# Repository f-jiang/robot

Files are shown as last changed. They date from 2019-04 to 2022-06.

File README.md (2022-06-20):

# Mobile Robot

[BOM](https://docs.google.com/spreadsheets/d/1hAyx_H2yaLHObjr3c2HcGa4GbXQhFF7O3Fq-fULQeV0/edit?usp=sharing)
[Google Drive](https://drive.google.com/drive/folders/1Uw0iWY_K3mZgV3rem3GLMkO6ajqQ58nl)

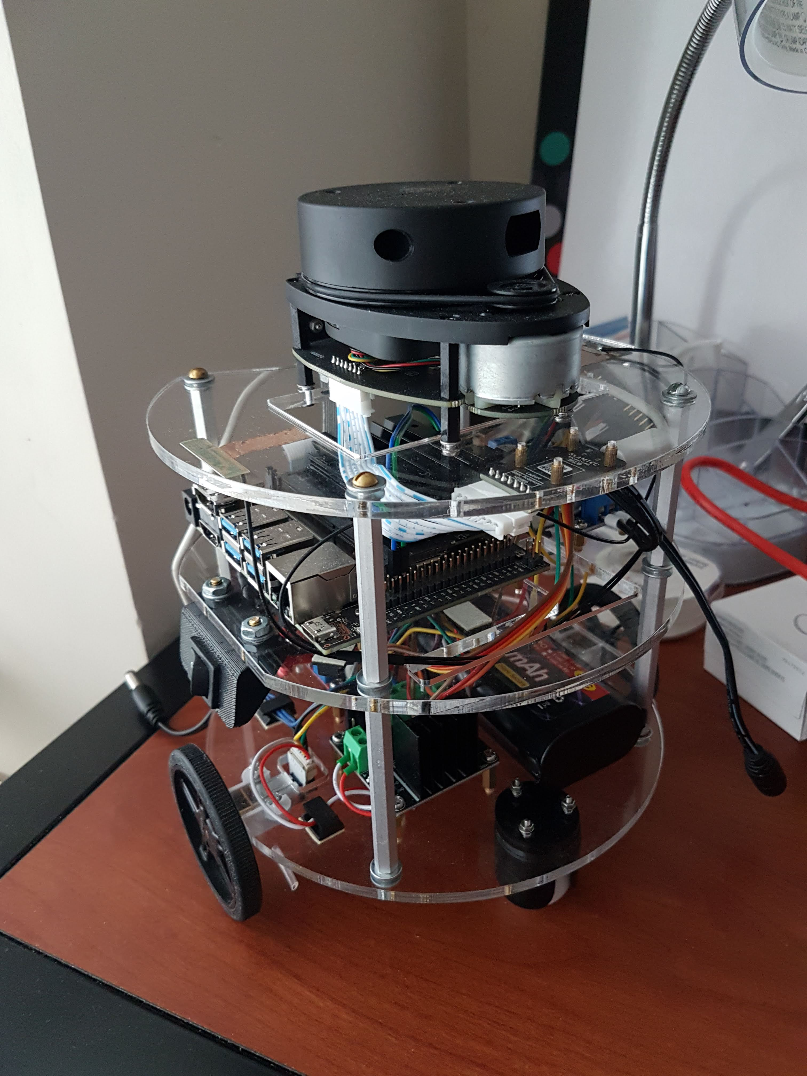
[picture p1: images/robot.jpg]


### Contributors:

- Feilan Jiang
- Matt Strong
- Tejit Pabari
- Satish Upadhyaya

## Requirements

- ROS Melodic

## Setup

```bash
# create a catkin workspace
mkdir -p catkin_ws/src
cd catkin_ws/src
git clone https://github.com/f-jiang/robot
cd ..

# automatically install the packages
rosdep install --from-paths src --ignore-src -r -y

# build the workspace
catkin build 
# or catkin_make

# it is recommended to add the below line to your ~/.bashrc
source devel/setup.bash
```

## Running the Simulation 

```bash
# run the simulation
roslaunch world_name:=worlds/rooms.world use_gazebo:=true robot_base base.launch

# run teleop; keyboard controls will start in same terminal window
roslaunch use_gazebo:=true robot_control teleop.launch
```

This is how the simulation should look:

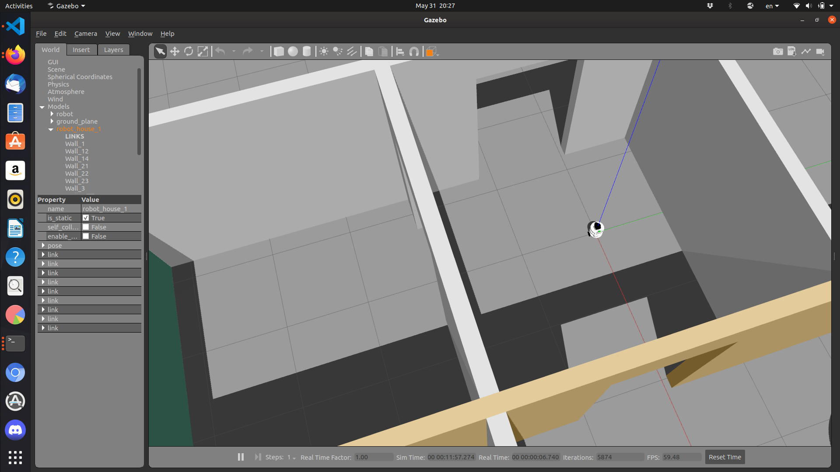
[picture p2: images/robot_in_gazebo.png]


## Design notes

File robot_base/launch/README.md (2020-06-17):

# `robot_base` launch files

- `base.launch`: Top-level launch file. Starts up all nodes required to interface with robot actuators and sensors, whether in real-life or simulation. Also loads robot description to allow for publishing of tf frames. Can be launched directly (will need to provide a `cmd_vel` msg).
- `drive_base.launch`: Launches nodes required to drive the robot, whether in real-life or simulation. Can be launched directly if wishing to drive the physical robot without sensors, and will need to provide a `cmd_vel` msg.
- `sensors_base.launch`: Launches sensors on the physical robot. Can be launched directly, although `tf` won't work.
- `robot_hw.launch`: Launches firmware node and PID controllers on the physical robot. Not meant to be launched directly.
- `tune_pid.launch`: Utility for tuning robot's PID controllers.

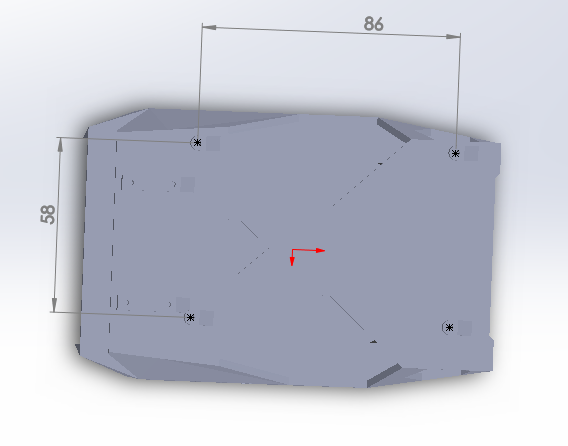
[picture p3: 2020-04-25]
cad/misc/Screenshot_1.png

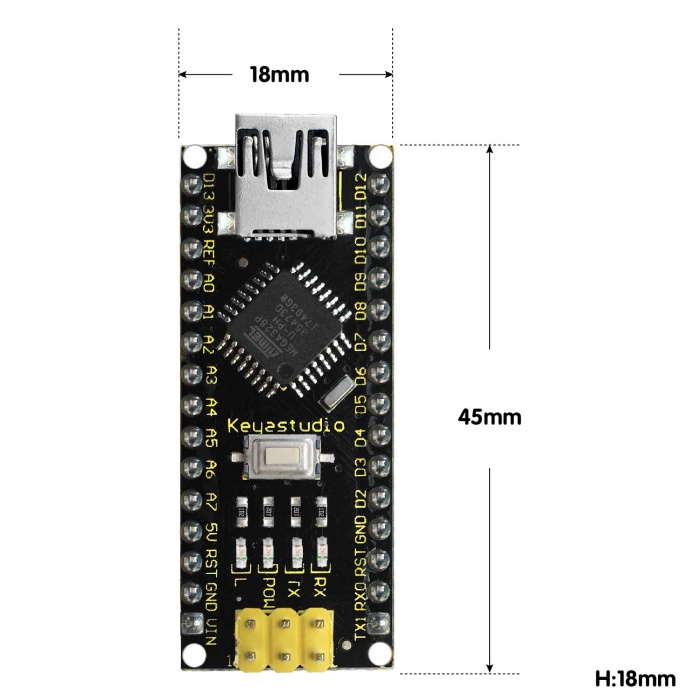
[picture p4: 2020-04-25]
cad/misc/700px-Ks0173_size.jpg

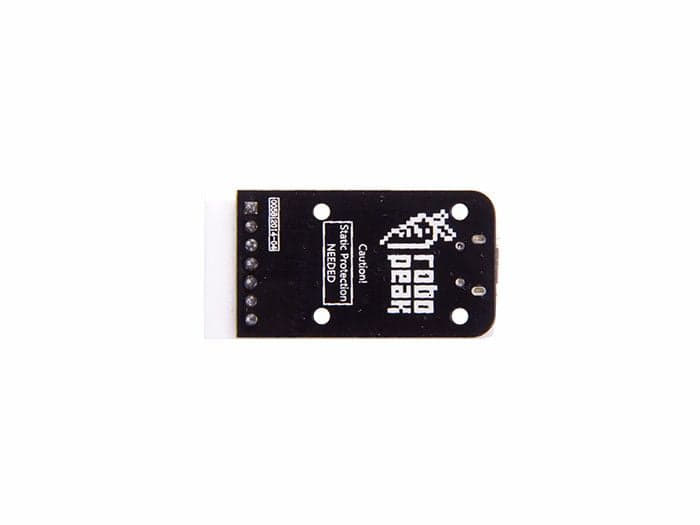
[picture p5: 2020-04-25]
cad/misc/lidar-usb-board.jpg

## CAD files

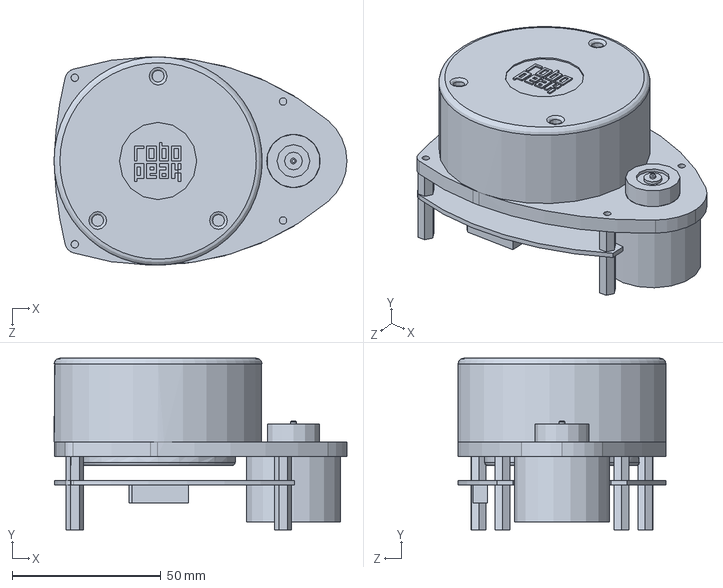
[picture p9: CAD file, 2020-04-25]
cad/ext parts/RPLidar_by_RoboPeak/files/rplidar_main.SLDPRT
98.5 x 57.7 x 70.0 mm

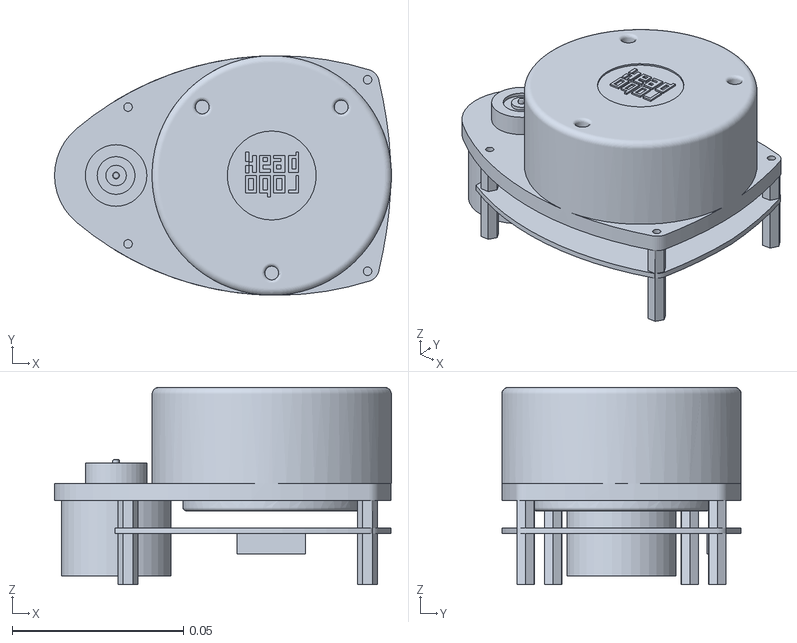
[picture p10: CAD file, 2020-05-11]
robot_description/meshes/rplidar_main.STL
0.0985 x 0.07 x 0.0577

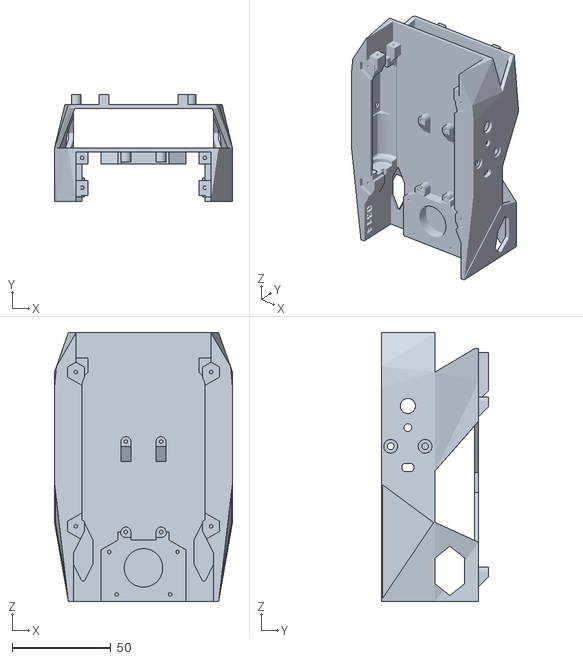
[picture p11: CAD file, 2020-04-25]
cad/ext parts/chassis.stl
90.0 x 54.0 x 136.0

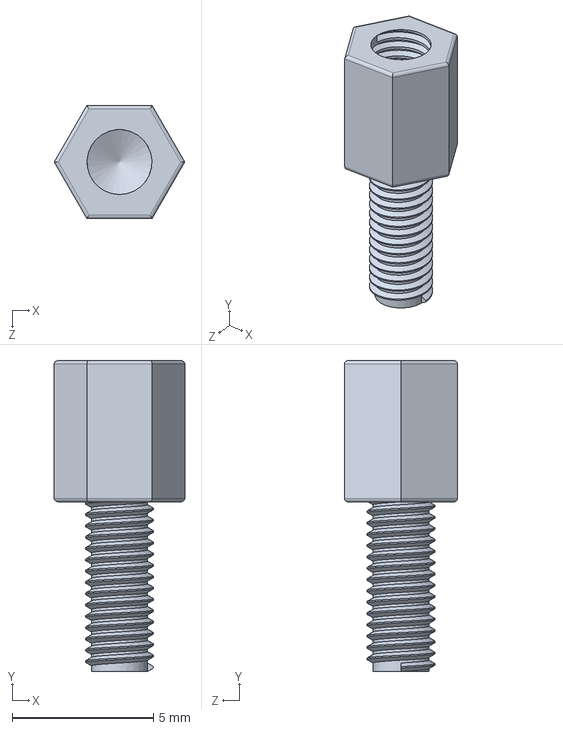
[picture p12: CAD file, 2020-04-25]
cad/ext parts/M2 Standoff mf.SLDPRT
4.62 x 11.0 x 4.00 mm

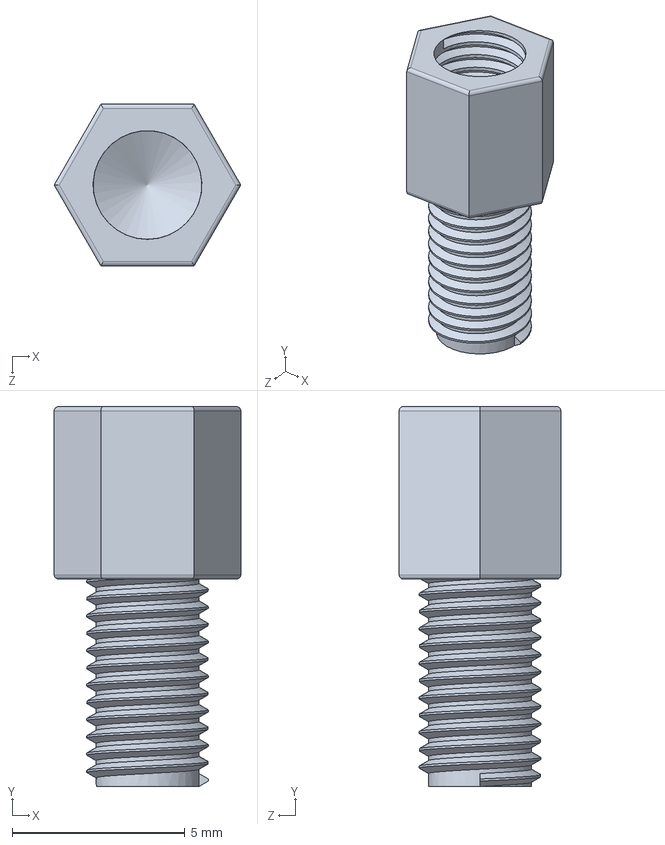
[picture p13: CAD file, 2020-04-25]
cad/ext parts/M3 Standoff mf.SLDPRT
5.40 x 11.0 x 4.68 mm

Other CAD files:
cad/export dwg/chassis-top-v2.DWG
cad/export dwg/chassis-mid.DWG
cad/export dwg/chassis-top.DWG
cad/3d print/camera-mount.SLDPRT
cad/3d print/export stl/arduino-nano-mount.STL
cad/3d print/export stl/camera-mount.STL
cad/3d print/export stl/caster-spacer 2.STL
cad/3d print/export stl/caster-spacer.STL
cad/3d print/export stl/old/camera-mount-slide-fit.STL
cad/3d print/export stl/switch-mount.STL
cad/3d print/old/camera-mount-slide-fit-old.SLDPRT
cad/3d print/old/camera-mount-slide-fit.SLDPRT
cad/3d print/old/camera-mount-snap-fit.SLDPRT
cad/arduino-nano-mount.SLDPRT
cad/battery.SLDPRT
cad/buck-drivetrain.SLDPRT
cad/caster.SLDPRT
cad/chassis.SLDPRT
cad/computer-buck.SLDPRT
cad/ext parts/RPLidar_by_RoboPeak/files/rplidar_main.STL
cad/imu.SLDPRT
cad/jetson.SLDPRT
cad/l298.SLDPRT
cad/lidar-adapter.SLDPRT
cad/lidar.SLDPRT
cad/motor-and-encoder.SLDPRT
cad/motor-bracket.SLDPRT
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

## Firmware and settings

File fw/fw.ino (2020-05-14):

#include <ros.h>
#include <std_msgs/Float64.h>

#include <stdio.h>

#include <Arduino.h>

// NOTE: currently this lib and the encoder code here rely on an unreleased fix for the arduino mbed core:
// https://github.com/arduino/ArduinoCore-nRF528x-mbedos/pull/69
#include <QuadratureEncoder.h>  // fork: f-jiang/QuadratureEncoder

// #define DEBUG

#define MOTOR_LB    8   // left backwards
#define MOTOR_LF    9   // left forward
#define MOTOR_RB    6   // right backwards
#define MOTOR_RF    7   // right forward
#define MOTOR_SLEEP 10
#define MOTOR_FAULT 11

#define ENC_LEFT_A  4
#define ENC_LEFT_B  5
#define ENC_RIGHT_A 2
#define ENC_RIGHT_B 3

#define ENC_PULSES_PER_REVOLUTION (51.45 * 12)

Encoders encLeft(ENC_LEFT_A, ENC_LEFT_B);
Encoders encRight(ENC_RIGHT_A, ENC_RIGHT_B);
unsigned long encLastTime;
long positionLeft = 0;
long positionRight = 0;

int loopDelay = 10;

char buf[256];

#ifndef DEBUG
// TODO integrate this into catkin so that robot_constants can be used here

ros::NodeHandle nh;

std_msgs::Float64 leftPosMsg;
ros::Publisher pubLeftPos("/left_wheel/pos", &leftPosMsg);

std_msgs::Float64 rightPosMsg;
ros::Publisher pubRightPos("/right_wheel/pos", &rightPosMsg);

std_msgs::Float64 leftVelMsg;
ros::Publisher pubLeftVel("/left_wheel/vel", &leftVelMsg);

std_msgs::Float64 rightVelMsg;
ros::Publisher pubRightVel("/right_wheel/vel", &rightVelMsg);

void leftEffCallback(const std_msgs::Float64& msg);
void rightEffCallback(const std_msgs::Float64& msg);
ros::Subscriber<std_msgs::Float64> subLeftEff("/left_wheel/control_effort", &leftEffCallback);
ros::Subscriber<std_msgs::Float64> subRightEff("/right_wheel/control_effort", &rightEffCallback);

int controlFrequency = 100;

void setMotor(byte fwdPin, byte bkdPin, short val) {
    short absVal = abs(val);
    if (val > 0) {
        analogWrite(fwdPin, absVal);
        analogWrite(bkdPin, 0);
    } else {
        analogWrite(fwdPin, 0);
        analogWrite(bkdPin, absVal);
    }
}

void leftEffCallback(const std_msgs::Float64& msg) {
    setMotor(MOTOR_LF, MOTOR_LB, round(msg.data));
}

void rightEffCallback(const std_msgs::Float64& msg) {
    setMotor(MOTOR_RF, MOTOR_RB, round(msg.data));
}
#endif

// rad/s
float angularVelocity(const long& oldPosition,
                      const long& newPosition,
                      const unsigned long& oldTime,
                      const unsigned long& newTime) {
    return (newPosition - oldPosition)
           / ENC_PULSES_PER_REVOLUTION
           * (PI * 2)
           / ((newTime - oldTime) / 1000.0f);
}

float angularPosition(const long& position) {
    long wrappedPosition = position
                           - static_cast<long>(position / ENC_PULSES_PER_REVOLUTION)
                           * ENC_PULSES_PER_REVOLUTION;

    if (position < 0) {
        wrappedPosition += ENC_PULSES_PER_REVOLUTION;
    }

    return wrappedPosition
           / ENC_PULSES_PER_REVOLUTION
           * (PI * 2);
}

void setup()
{
#ifdef DEBUG
    Serial.begin(115200);
#endif

    pinMode(MOTOR_SLEEP, OUTPUT);
    pinMode(MOTOR_FAULT, INPUT);
    pinMode(MOTOR_LB, OUTPUT);
    pinMode(MOTOR_LF, OUTPUT);
    pinMode(MOTOR_RB, OUTPUT);
    pinMode(MOTOR_RF, OUTPUT);

    // motors off
    analogWrite(MOTOR_LB, 0);
    analogWrite(MOTOR_LF, 0);
    analogWrite(MOTOR_RB, 0);
    analogWrite(MOTOR_RF, 0);

    // disable low-power sleep mode
    digitalWrite(MOTOR_SLEEP, HIGH);

#ifndef DEBUG
    nh.initNode();

    nh.advertise(pubLeftPos);
    nh.advertise(pubRightPos);
    nh.advertise(pubLeftVel);
    nh.advertise(pubRightVel);

    nh.subscribe(subLeftEff);
    nh.subscribe(subRightEff);

    while (!nh.connected()) {
        nh.spinOnce();
    }

    // TODO robot_constants::params::kControlFrequency
    nh.getParam("/control_frequency", &controlFrequency);
    sprintf(buf, "fw_node running at %d hz", controlFrequency);
    nh.loginfo(buf);
    loopDelay = round(1000 / static_cast<double>(controlFrequency));
#endif

    delay(1000);
}

void loop()
{
    long newPositionLeft, newPositionRight;
    float angularPositionLeft, angularPositionRight;
    float angularVelocityLeft, angularVelocityRight;
    newPositionLeft = -encLeft.getEncoderCount();
    newPositionRight = encRight.getEncoderCount();
    unsigned long encNow = millis();
    angularVelocityLeft = angularVelocity(positionLeft, newPositionLeft, encLastTime, encNow);
    angularVelocityRight = angularVelocity(positionRight, newPositionRight, encLastTime, encNow);
    angularPositionLeft = angularPosition(newPositionLeft);
    angularPositionRight = angularPosition(newPositionRight);

#ifdef DEBUG
    sprintf(buf,
            "pos_l: %6d, e_l: %6d, theta_l (deg): %4f, omega_l (deg/s): %8.2f, n_l (rpm): %8.2f, "
                "pos_r: %6d, e_r: %6d, theta_r (deg): %4f, omega_r (deg/s): %8.2f, n_r (rpm): %8.2f\n",
            newPositionLeft,
            encLeft.getEncoderErrorCount(),
            angularPositionLeft * 180 / PI,
            angularVelocityLeft * 180 / PI,
            angularVelocityLeft / (2 * PI) * 60,
            newPositionRight,
            encRight.getEncoderErrorCount(),
            angularPositionRight * 180 / PI,
            angularVelocityRight * 180 / PI,
            angularVelocityRight / (2 * PI) * 60);
    Serial.print(buf);
#endif

    encLastTime = encNow;
    positionLeft = newPositionLeft;
    positionRight = newPositionRight;

#ifndef DEBUG
    leftPosMsg.data = angularPositionLeft;
    pubLeftPos.publish(&leftPosMsg);
    rightPosMsg.data = angularPositionRight;
    pubRightPos.publish(&rightPosMsg);

    leftVelMsg.data = angularVelocityLeft;
    pubLeftVel.publish(&leftVelMsg);
    rightVelMsg.data = angularVelocityRight;
    pubRightVel.publish(&rightVelMsg);

    nh.spinOnce();
#endif

    delay(loopDelay);
}

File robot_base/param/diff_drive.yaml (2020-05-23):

type        : "diff_drive_controller/DiffDriveController"
left_wheel  : 'base_to_left_wheel_joint'  # joint 0
right_wheel : 'base_to_right_wheel_joint' # joint 1
pose_covariance_diagonal : [0.001, 0.001, 1000000.0, 1000000.0, 1000000.0, 1000.0]  # TODO adjust
twist_covariance_diagonal: [0.001, 0.001, 1000000.0, 1000000.0, 1000000.0, 1000.0]

wheel_separation : 0.17923
wheel_radius : 0.03

linear:
  x:
    has_velocity_limits: true
    max_velocity: 0.5
angular:
  z:
    has_velocity_limits: true
    max_velocity: 1.5

# TODO publish rate /control_frequency
base_frame_id: base_link
enable_odom_tf: true
odom_frame_id: odom
publish_cmd: true

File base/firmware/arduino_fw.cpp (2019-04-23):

#include <Arduino.h>

#include <Encoder.h>

#define private public
#include <PID_v1.h>
#undef private

// TODO set and correct all names
#define MOTOR_LEFT_EN 11    // EN_B
#define MOTOR_RIGHT_EN 10   // EN_A
#define MOTOR_IN_1 6
#define MOTOR_IN_2 9
#define MOTOR_IN_3 12
#define MOTOR_IN_4 13

// ENC PINS
#define ENC_LEFT_A  2
#define ENC_LEFT_B  7
#define ENC_RIGHT_A 3
#define ENC_RIGHT_B 8

#define ENC_PULSES_PER_REVOLUTION 420

struct PidController {
    double input = 0;   // TODO private w/ getters
    double output = 0;
    double setpoint = 0;
    PID controller = PID(&input, &output, &setpoint, 0, 0, 0, DIRECT);
};

Encoder encLeft(ENC_LEFT_A, ENC_LEFT_B);
Encoder encRight(ENC_RIGHT_A, ENC_RIGHT_B);
unsigned long encLastTime;
long positionLeft = 0;
long positionRight = 0;

PidController pidLeft;
PidController pidRight;

// rad/s
float angularVelocity(const long& oldPosition,
                      const long& newPosition,
                      const unsigned long& oldTime,
                      const unsigned long& newTime) {
    return (newPosition - oldPosition)
           / static_cast<float>(ENC_PULSES_PER_REVOLUTION)
           * (PI * 2)
           / ((newTime - oldTime) / 1000.0f);
}

void setup()
{
    Serial.begin(57600);

    // MOTOR SETUP
    pinMode(MOTOR_RIGHT_EN, OUTPUT);
    pinMode(MOTOR_LEFT_EN, OUTPUT);
    pinMode(MOTOR_IN_1, OUTPUT);
    pinMode(MOTOR_IN_2, OUTPUT);
    pinMode(MOTOR_IN_3, OUTPUT);
    pinMode(MOTOR_IN_4, OUTPUT);

    pidLeft.input = 0;
    pidLeft.setpoint = 0;
    pidLeft.controller.SetMode(AUTOMATIC);
    pidLeft.controller.SetOutputLimits(-255, 255);
    pidLeft.controller.SetTunings(2.5, 0, 0);

    pidRight.input = 0;
    pidRight.setpoint = 0;
    pidRight.controller.SetMode(AUTOMATIC);
    pidRight.controller.SetOutputLimits(-255, 255);
    pidRight.controller.SetTunings(2.5, 0, 0);

    delay(3000);
}

void loop()
{
    // ENCODER
    long newPositionLeft, newPositionRight;
    float angularVelocityLeft, angularVelocityRight;
    newPositionLeft = encLeft.read();   // mod?
    newPositionRight = -encRight.read();    // correct direction
    unsigned long encNow = millis();
    angularVelocityLeft = angularVelocity(positionLeft, newPositionLeft, encLastTime, encNow);
    angularVelocityRight = angularVelocity(positionRight, newPositionRight, encLastTime, encNow);
    Serial.print("pos Left = ");
    Serial.print(newPositionLeft);
    Serial.print(", pos Right = ");
    Serial.print(newPositionRight);
    Serial.print(", ang vel Left (rad/s) = ");
    Serial.print(angularVelocityLeft);
    Serial.print(", ang vel Right (rad/s) = ");
    Serial.print(angularVelocityRight);
    Serial.print(", ang vel Left (deg/s) = ");
    Serial.print(angularVelocityLeft * 180 / PI);
    Serial.print(", ang vel Right (deg/s) = ");
    Serial.print(angularVelocityRight * 180 / PI);
    Serial.print(", ang vel Left (rpm) = ");
    Serial.print(angularVelocityLeft / (2 * PI) * 60);
    Serial.print(", ang vel Right (rpm) = ");
    Serial.print(angularVelocityRight / (2 * PI) * 60);
    Serial.println();
    encLastTime = encNow;
    positionLeft = newPositionLeft;
    positionRight = newPositionRight;
    // serial write out (ang) vel, and pos

    // PID
#define RPM_TO_RAD_S(val)   (val / 60.0f * 2 * PI)
    pidLeft.input = angularVelocityLeft;
    pidLeft.setpoint = RPM_TO_RAD_S(-200);
    pidLeft.controller.Compute();
    pidRight.input = angularVelocityRight;
    pidRight.setpoint = RPM_TO_RAD_S(-200);
    pidRight.controller.Compute();
#undef  RAD_S_TO_RPM

    // left motor
    int leftMotorValue = abs(pidLeft.output);
    // forward
    if (pidLeft.output > 0) {
        digitalWrite(MOTOR_IN_1, LOW);
        digitalWrite(MOTOR_IN_2, HIGH);
    // backward
    } else {
        digitalWrite(MOTOR_IN_1, HIGH);
        digitalWrite(MOTOR_IN_2, LOW);
    }
    // TODO deadzone
    analogWrite(MOTOR_LEFT_EN, leftMotorValue);

    // right motor
    int rightMotorValue = abs(pidRight.output);
    // forward
    if (pidRight.output > 0) {
        digitalWrite(MOTOR_IN_3, HIGH);
        digitalWrite(MOTOR_IN_4, LOW);
    // backward
    } else {
        digitalWrite(MOTOR_IN_3, LOW);
        digitalWrite(MOTOR_IN_4, HIGH);
    }
    analogWrite(MOTOR_RIGHT_EN, rightMotorValue);

    delay(50);
}

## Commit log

2019-04-23 setup: add cmake files for arduino
2019-04-23 fw: add motor and encoder code with untuned pids
2019-04-28 fw: fw updates
    - remove fw from catkin build system
    - basic pid tune
    - add serial comms
2019-04-28 fw: serial updates
    - parse incoming data into pid setpoint
    - write eol for outgoing data
2019-04-30 fw: add delay to arduino to make it sync with ros node
2019-05-05 teleop: add teleop required nodes etc
    - diff_drive_controller
    - joy
    - teleop_twist_joy
    - base_node
    - serial_node
    [robot_base.yaml]
2019-05-08 teleop: add sensor feeds and rviz config
2020-04-25 add cad and notes
    [6-32 standoff ff.SLDPRT, M2 Standoff mf.SLDPRT, M3 Standoff mf.SLDPRT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]
2020-04-26 fw: update for new arduino board and motors
2020-04-27 teleop: find working camera driver package
2020-04-28 install pid pkg
2020-04-28 reorganize base and control packages
    - move all controller-related content to robot_base
    - create sensors launch file in robot_base
    [robot_base.yaml]
2020-04-29 implement pid and fw_node pub/sub
    [robot_base.yaml]
2020-04-30 revisions to drive controller and fw
    fw:
    - fix control_effort topic references in fw
    - make fw get loop frequency from param /control_frequency
    - limit angular position to [0, 2 * pi]
    - publish angular velocity and position
    robot_base:
    - reorder hw_base.launch for fw_node to read params properly
    - add timeout param for read()
    robot_constants:
    - create top-level header
    - create params header
    [fw.ino]
2020-05-01 fw: correct motor pins after chassis direction reversal
    [fw.ino]
2020-05-01 fw: fix control bug involving negative analog values
    [fw.ino]
2020-05-01 teleop: increase turn speed
    [robot_base.yaml]
2020-05-01 teleop: implement setpoint sliders for pid tuner
    [Setpoint.cfg]
2020-05-02 update base_controller wheel radius
    [robot_base.yaml]
2020-05-05 fw: correct wheel angle calc
    [fw.ino]
2020-05-07 teleop: roughly tuned hw pid
2020-05-08 fw: fix debug print for wheel degree
    [fw.ino]
2020-05-09 cad: dissolve unnecessary subassemblies
    [robot.SLDASM]
2020-05-09 sim: add robot desc with collision properties
    [robot.xacro]
2020-05-09 sim: xacro-ize robot desc
    [robot.xacro]
2020-05-10 create new pkg robot_description
    [robot.xacro]
2020-05-10 sim: add transmissions to urdf
    [robot.xacro]
2020-05-10 sim: make joint names consistent
    [robot.xacro, robot_base.yaml]
2020-05-11 sim: add gazebo material properties
    [robot.xacro]
2020-05-11 sim: make adjustments to urdf
    - link gazebo_ros_control
    - fix wheel poses so revolutions are in the same direction
    - specify VelocityJointInterface name
    [robot.xacro]
2020-05-11 sim: move urdf materials into own file
    [materials.xacro, robot.xacro]
2020-05-11 cad: secure camera mount in asm
    [robot.SLDASM]
2020-05-11 cad: add camera to asm
    [robot.SLDASM]
2020-05-11 sim: add sensor links
    [camera.SLDPRT, materials.xacro, robot.gazebo.xacro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]
2020-05-11 sim: rename robot.xacro
    [robot.urdf.xacro]
2020-05-11 sim: define sensor colors in gazebo
    [robot.gazebo.xacro]
2020-05-11 sim: add camera plugin
    [robot.gazebo.xacro, robot.urdf.xacro]
2020-05-11 sim: add laser plugin
    [robot.gazebo.xacro]
2020-05-11 make sensor topic names consistent between rim and real-life
    [robot.gazebo.xacro]
2020-05-11 rename and organize yaml controllers
    [Setpoint.cfg, robot_base.yaml]
2020-05-11 sim: make sensor tf frames consistent between sim and real life
2020-05-12 sim: add sensor feeds to rviz
2020-05-12 make Setpoint.cfg executable
    resolves robot_base build error
    [Setpoint.cfg]
2020-05-12 always publish joint states including wheels
2020-05-14 teleop: fix viz issues
    - tf
    - sensor feeds
    - lidar backwards
    [robot.urdf.xacro]
2020-05-23 make casters continuous
    [robot.urdf.xacro]
2020-05-24 teleop: reduce camera feed lag
2020-06-07 Revert "make casters continuous"
    This reverts commit 3a9c5f69ece680231ff0b49033c50956b40bbc0b.
    [robot.urdf.xacro]
2020-06-07 set caster wheel friction to 0
    - with continuous joint robot would wobble when turning
    - frictionless but fixed caster is best approximation for spherical caster
    [robot.gazebo.xacro]
2020-06-07 sim: hide laser scan visualization in gazebo
    [robot.gazebo.xacro]
2022-06-20 add joystick device arg
